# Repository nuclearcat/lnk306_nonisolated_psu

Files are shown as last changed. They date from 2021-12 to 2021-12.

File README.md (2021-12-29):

# lnk306_nonisolated_psu
WARNING! This is an non-isolated power supply, so even the DC output will have a dangerous mains potential.
Do not use it unless you know the difference between isolated or non-isolated power supply.

TBD: Dont use current version yet, small mistake in BOM for connectors, will fix it soon

My goal was to obtain a DC-DC supply with a very wide operating voltage range. 
On tests with 5v output, this power supply provides enough voltage for esp32 starting from 20v input voltage (DC)

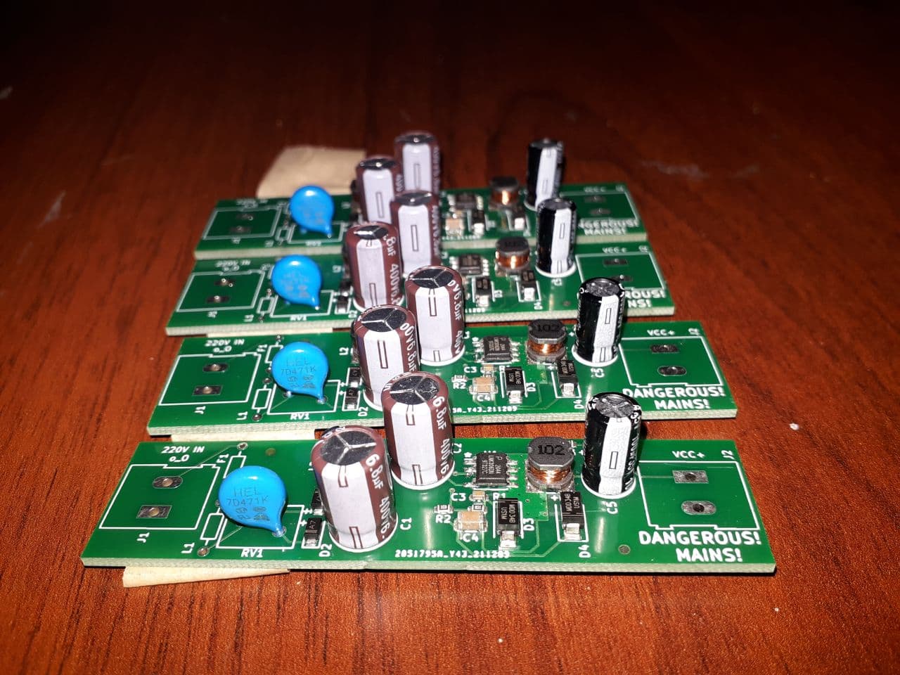
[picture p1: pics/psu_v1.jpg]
Drag Racing


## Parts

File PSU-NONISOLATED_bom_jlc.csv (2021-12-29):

Comment | Designator | Footprint | LCSC Part #
4.7u | C1,C2 | CP_Radial_D8.0mm_P3.50mm | C112471
100n | C3 | C_0603_1608Metric | C77055
10u | C4 | C_1206_3216Metric | C13585
100u | C5 | CP_Radial_D6.3mm_P2.50mm | C19504
4007 | D1,D2 | D_SOD-123F | C64898
US1M | D3,D4 | D_SMA | C412437
LED | D5 | LED_0603_1608Metric | C2286
Mains | J1 | TerminalBlock_Altech_AK300-2_P5.00mm | C72334
DC | J2 | TerminalBlock_Altech_AK300-2_P5.00mm | C72334
MSA54-102M | L2,L3 | L_TracoPower_TCK-047_5.2x5.8mm | C396419
2k | R1,R2 | R_0603_1608Metric | C22975
1k | R3 | R_0603_1608Metric | C21190
Varistor | RV1 | RV_Disc_D9mm_W6.1mm_P5mm | C111187
LNK306D | U1 | PowerIntegrations_SO-8C | C34318

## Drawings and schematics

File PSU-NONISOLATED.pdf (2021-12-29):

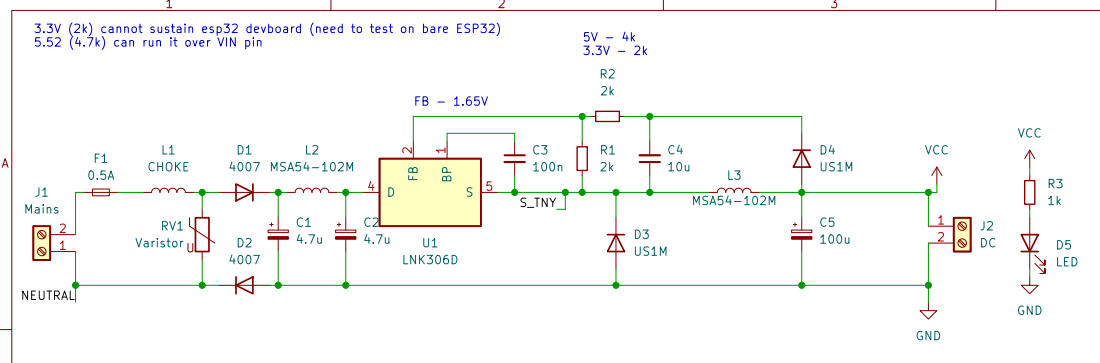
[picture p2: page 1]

3.3V (2k) cannot sustain esp32 devboard (need to test on bare ESP32)
5.52 (4.7k) can run it over VIN pin

File: PSU-NONISOLATED.kicad_sch Sheet: /
Id: 1/1 Title:

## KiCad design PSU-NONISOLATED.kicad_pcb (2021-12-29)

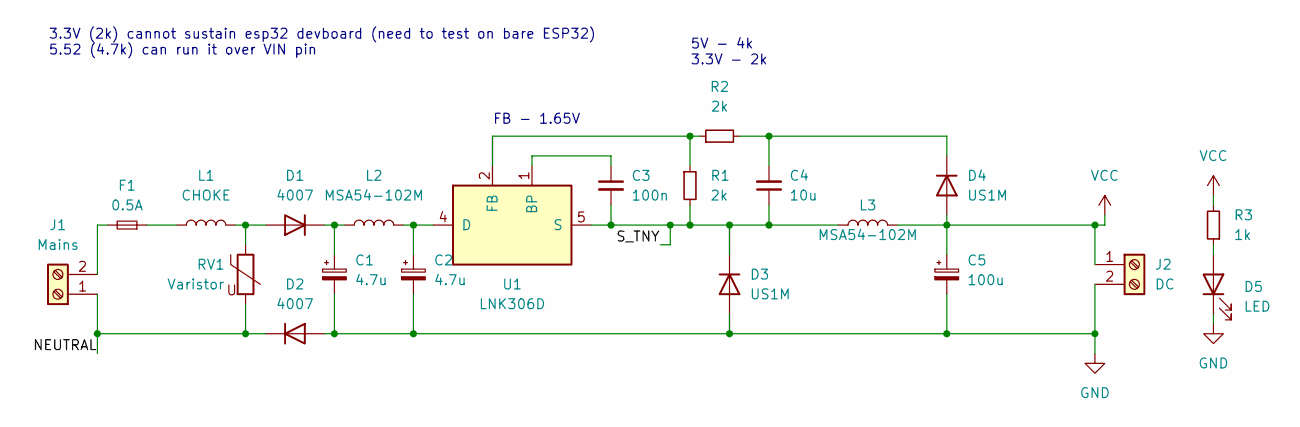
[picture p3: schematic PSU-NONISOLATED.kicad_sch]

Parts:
C1, C2: 4.7u; CP_Radial_D8.0mm_P3.50mm; LCSC PN C112471
C3: 100n; C_0603_1608Metric; LCSC PN C77055
C4: 10u; C_1206_3216Metric; LCSC PN C13585
C5: 100u; CP_Radial_D6.3mm_P2.50mm; LCSC PN C19504
D1, D2: 4007; D_SOD-123F; LCSC PN C64898
D3, D4: US1M; D_SMA; LCSC PN C412437
D5: LED; LED_0603_1608Metric; LCSC PN C2286
F1: 0.5A; R_Axial_DIN0204_L3.6mm_D1.6mm_P7.62mm_Horizontal
J1: Mains; TerminalBlock_Altech_AK300-2_P5.00mm; LCSC PN C72334
J2: DC; TerminalBlock_Altech_AK300-2_P5.00mm; LCSC PN C72334
L1: CHOKE; R_Axial_DIN0204_L3.6mm_D1.6mm_P7.62mm_Horizontal
L2, L3: MSA54-102M; L_TracoPower_TCK-047_5.2x5.8mm; LCSC PN C396419
R1, R2: 2k; R_0603_1608Metric; LCSC PN C22975
R3: 1k; R_0603_1608Metric; LCSC PN C21190
RV1: Varistor; RV_Disc_D9mm_W6.1mm_P5mm; LCSC PN C111187
U1: LNK306D; PowerIntegrations_SO-8C; LCSC PN C34318

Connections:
/NEUTRAL: D2.1 (K), J1.1, RV1.2
/S_TNY: C3.2, C4.1, D3.1 (K), L3.1, R1.2, U1.5 (S), U1.6 (S), U1.7 (S), U1.8 (S)
GND: C1.2, C2.2, C5.2, D2.2 (A), D3.2 (A), D5.1 (K), J2.2
unnamed: C3.1, U1.1 (BP)
unnamed: C4.2, D4.1 (K), R2.2
unnamed: C1.1, D1.1 (K), L2.1
unnamed: D1.2 (A), L1.2, RV1.1
unnamed: D5.2 (A), R3.1
unnamed: F1.1, L1.1
unnamed: F1.2, J1.2
unnamed: C2.1, L2.2, U1.4 (D)
unnamed: R1.1, R2.1, U1.2 (FB)
VCC: C5.1, D4.2 (A), J2.1, L3.2, R3.2

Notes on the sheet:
3.3V (2k) cannot sustain esp32 devboard (need to test on bare ESP32) 5.52 (4.7k) can run it over VIN pin
FB - 1.65V
5V - 4k 3.3V - 2k

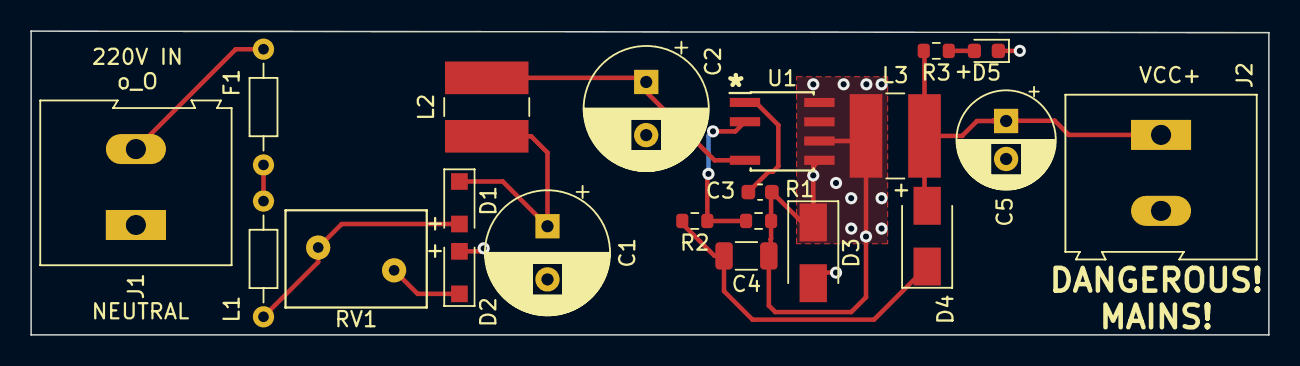
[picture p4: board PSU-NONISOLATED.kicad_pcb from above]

Board: 2 copper layers, 81.5 x 20.0 mm, 21 parts (0 on the bottom side), 13 nets.

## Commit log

2021-12-29 Working (tested) version
    [PSU-NONISOLATED.kicad_pcb, PSU-NONISOLATED.kicad_sch]
2021-12-29 Add schematics PDF and gerbers
    [PSU-NONISOLATED-B.Cu.gbr, PSU-NONISOLATED-B.Mask.gbr, PSU-NONISOLATED-B.Paste.gbr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]
2021-12-29 Description and some silkscreen for v2
    [PSU-NONISOLATED.kicad_pcb]
2021-12-29 Add BOM and CPL
    [PSU-NONISOLATED_bom_jlc.csv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]
